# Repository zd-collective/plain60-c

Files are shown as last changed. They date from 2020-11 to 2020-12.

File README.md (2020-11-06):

# Plain60-C rev2.2 (Noctus edition)

This universal 60% PCB is designed to support as little layouts as possible without limiting usability for most users. The reason I did this is because other PCBs made for this form factor usually have so many supported layouts that it could almost qualify as swiss cheese.

It also features a fuse and an ESD protection chip to protect the MCU and other parts of the PCB.

## Modifications

- modified to use the same JST header position as the WT60 by Wilba
- holes for mounting of the weight on the Noctus
- removed the usb type-c port and related hardware
- added silkscreen onto the front
- removed standard poker mounting holes
- removed speaker

## Features
- Compatible with QMK Firmware and VIA Configurator (if you flash a VIA compatible .hex file)
- JST header for connection with daughterboard
- No LEDs and no underglow
- Minimal layout support
- ISP header

## Supported layouts
Supported layouts of the Plain60-C

## Building
If you feel like building a few of these PCBs yourself, go to the 'Releases' tab and download the latest gerber files. Order those at your favourite PCB manufacturer, get the components needed (see below) and solder them on! A hot air station is not required but a soldering iron is. Flux is recommended.

## Opening the project
To open the files you will need the latest KiCAD nightly version.

## Bill of materials (BOM)
Amount is per PCB, multiply as needed.

| LCSC part # | Description | Value | Package  | Amount |
| --- | --- | ----- | --- | ---:|
| C128353 | Capacitor | 0.1uF | 0805 | 4 |
| C131056 | Capacitor | 4.7uF | 0805 | 1 |
| C215803 | Capacitor | 1uF | 0805 | 1 |
| C109001 | Diode | | 0805 | 65 |
| C261942 | Fuse | | 0805 | 1 |
| C165948 | Connector | | SMD/THT  | 1 |
| C103904 | Resistor | 10K | 0805 | 2 |
| C212411 | Resistor | 5.1K  | 0805 | 2 |
| C325772 | Resistor | 22 | 0805 | 2 |
| C44854 | MCU | 32U4  | QFP-44 | 1 |
| C7519 | ESD chip | | SOT23-6  | 1 |
| C341521 | Resonator | 16MHz | SMD | 1 |
| C92584 | Switch | | SMD | 1 |
| C160404 | Optional JST  | | SMD | 1 |

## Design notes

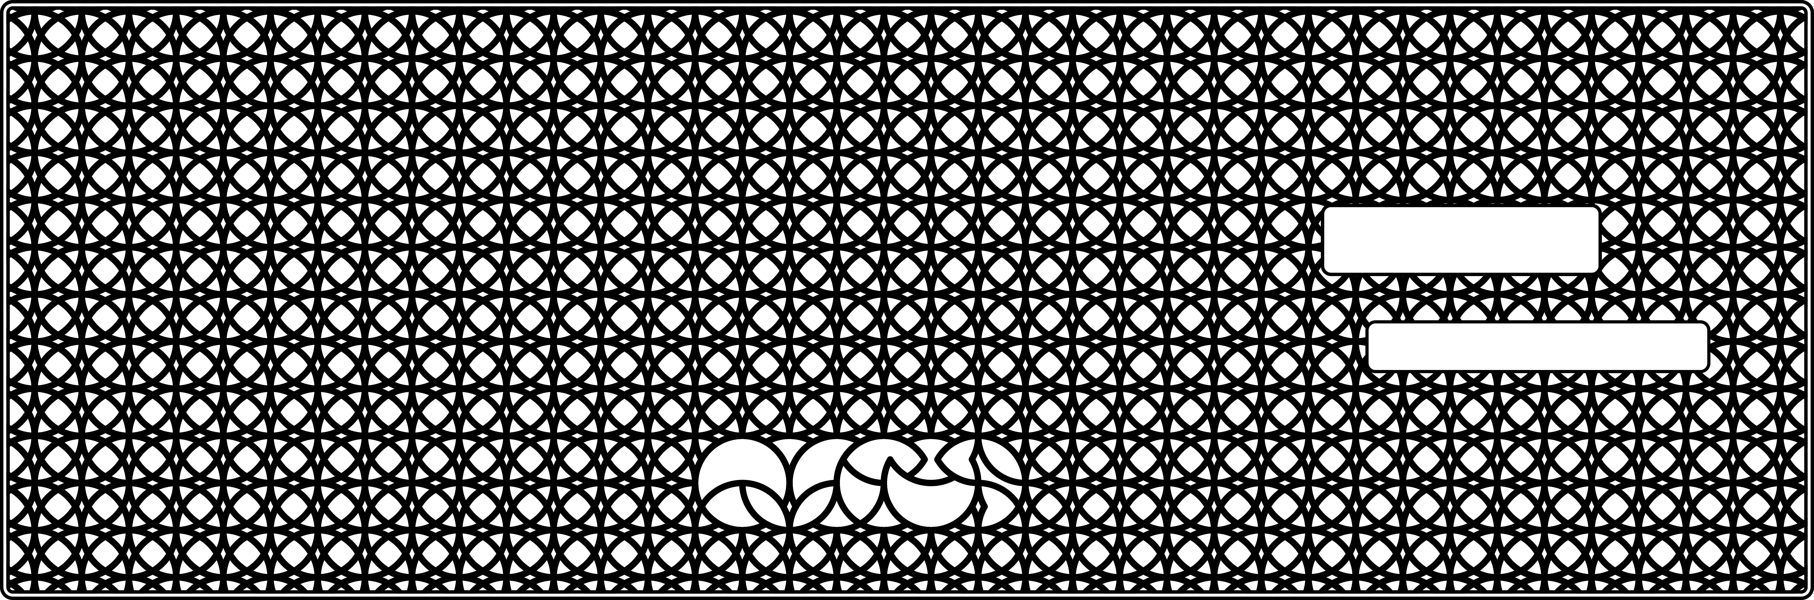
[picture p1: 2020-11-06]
noctus.png

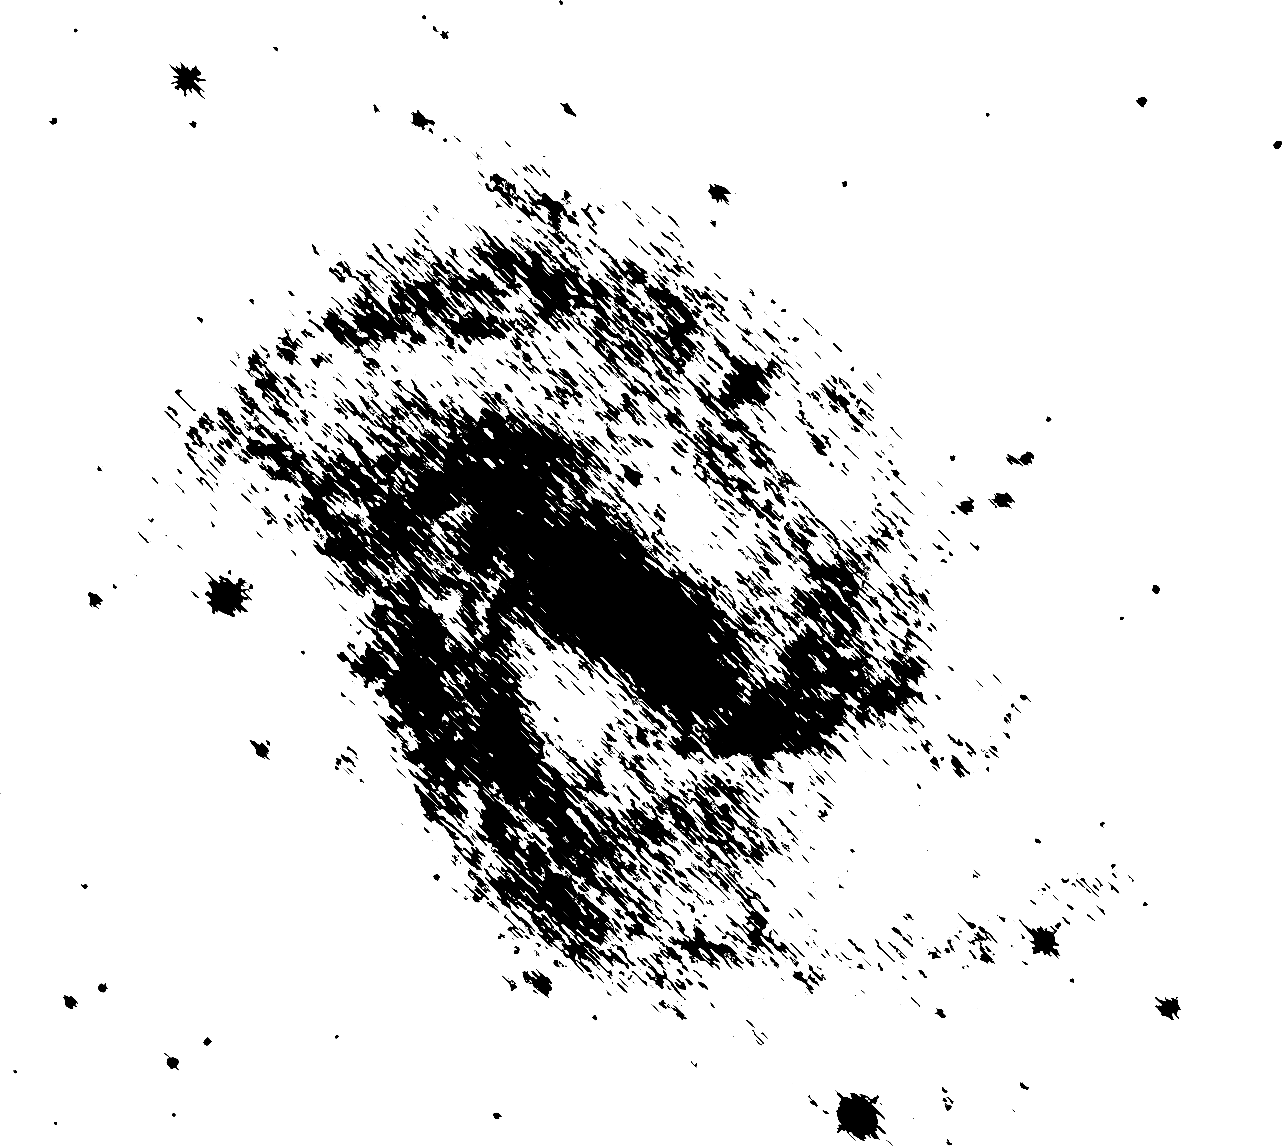
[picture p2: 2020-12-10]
galaxy.png

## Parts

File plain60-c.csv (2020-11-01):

Comment | Designator | Footprint | LCSC
1u | C1 | Keeb_components:C_0805
0.1u | C2,C3,C4,C5 | Keeb_components:C_0805
4.7u | C6 | Keeb_components:C_0805
D | D1,D2,D3,D4,D5,D6,D7,D8,D9,D10,D11,D12,D13,D14,D15,D16,D17,D18,D19,D20,D21,D22,D23,D24,D25,D26,D27,D28,D29,D31,D32,D33,D34,D35,D36,D37,D38,D39,D40,D41,D42,D43,D44,D46,D47,D48,D49,D50,D51,D52,D53,D54,D55,D56,D57,D58,D59,D61,D62,D63,D67,D71,D72,D73,D74 | Keeb_components:D_0805
Polyfuse | F1 | Keeb_components:R_0805
B0 | H1 | footprints:free_pin
GND | H3 | footprints:free_pin
+5v | H4 | footprints:free_pin
HRO-TYPE-C-31-M-12 | J1 | Keeb_components:HRO-TYPE-C-31-M-12
ISP | J2 | Keeb_components:isp_standard
ai03_ud | J3 | Keeb_components:JST_SH_SM04B-SRSS-TB_1x04-1MP_P1.00mm_Horizontal
KEYSW | K1,K2,K3,K4,K5,K6,K7,K8,K9,K10,K11,K12,K13,K14,K17,K18,K19,K20,K21,K22,K23,K24,K25,K26,K27,K28,K32,K33,K34,K35,K36,K37,K38,K39,K40,K41,K42,K43,K47,K48,K49,K50,K51,K52,K53,K54,K55,K56,K57,K59,K15-1,K62-1,K73-1 | Keeb_switches:CHERRY_PLATE_100H
KEYSW | K15 | Keeb_switches:CHERRY_PCB_200H
KEYSW | K16,K29,K61-1,K63-1,K72-1,K74-1 | Keeb_switches:CHERRY_PLATE_150H
KEYSW | K31,K58-1 | Keeb_switches:CHERRY_PLATE_175H
KEYSW | K44,K46 | Keeb_switches:CHERRY_PCB_225H
KEYSW | K44-1 | Keeb_switches:CHERRY_PCB_200H_V
KEYSW | K58 | Keeb_switches:CHERRY_PCB_275H
KEYSW | K61,K62,K63,K71,K72,K73,K74,K31-1,K46-1 | Keeb_switches:CHERRY_PLATE_125H
KEYSW | K67 | Keeb_switches:CHERRY_PCB_625H_F
KEYSW | K67-1 | Keeb_switches:CHERRY_PCB_700H_F
Speaker | LS1 | Keeb_components:speaker_AST1109MLTRQ
22 | R1,R2 | Keeb_components:R_0805
5.1k | R3,R4 | Keeb_components:R_0805
10k | R5,R6 | Keeb_components:R_0805
Screw | S1,S2,S3,S6 | footprints:5.5_5x2.5mm
Screw | S4,S5 | footprints:10x5_7x2.5mm
Tofu screw | S7,S8,S9 | footprints:5.5_5x2.5mm
SW_PUSH | SW1 | Button_Switch_SMD:SW_SPST_TL3342
ATmega32U4 | U1 | Keeb_components:ATMEGA32U4
USBLC6-2SC6 | U2 | Keeb_components:USBLC6-2SC6
XTAL_GND | X1 | Keeb_components:Resonator_SMD_muRata_CSTNExxV-3Pin-p1.2

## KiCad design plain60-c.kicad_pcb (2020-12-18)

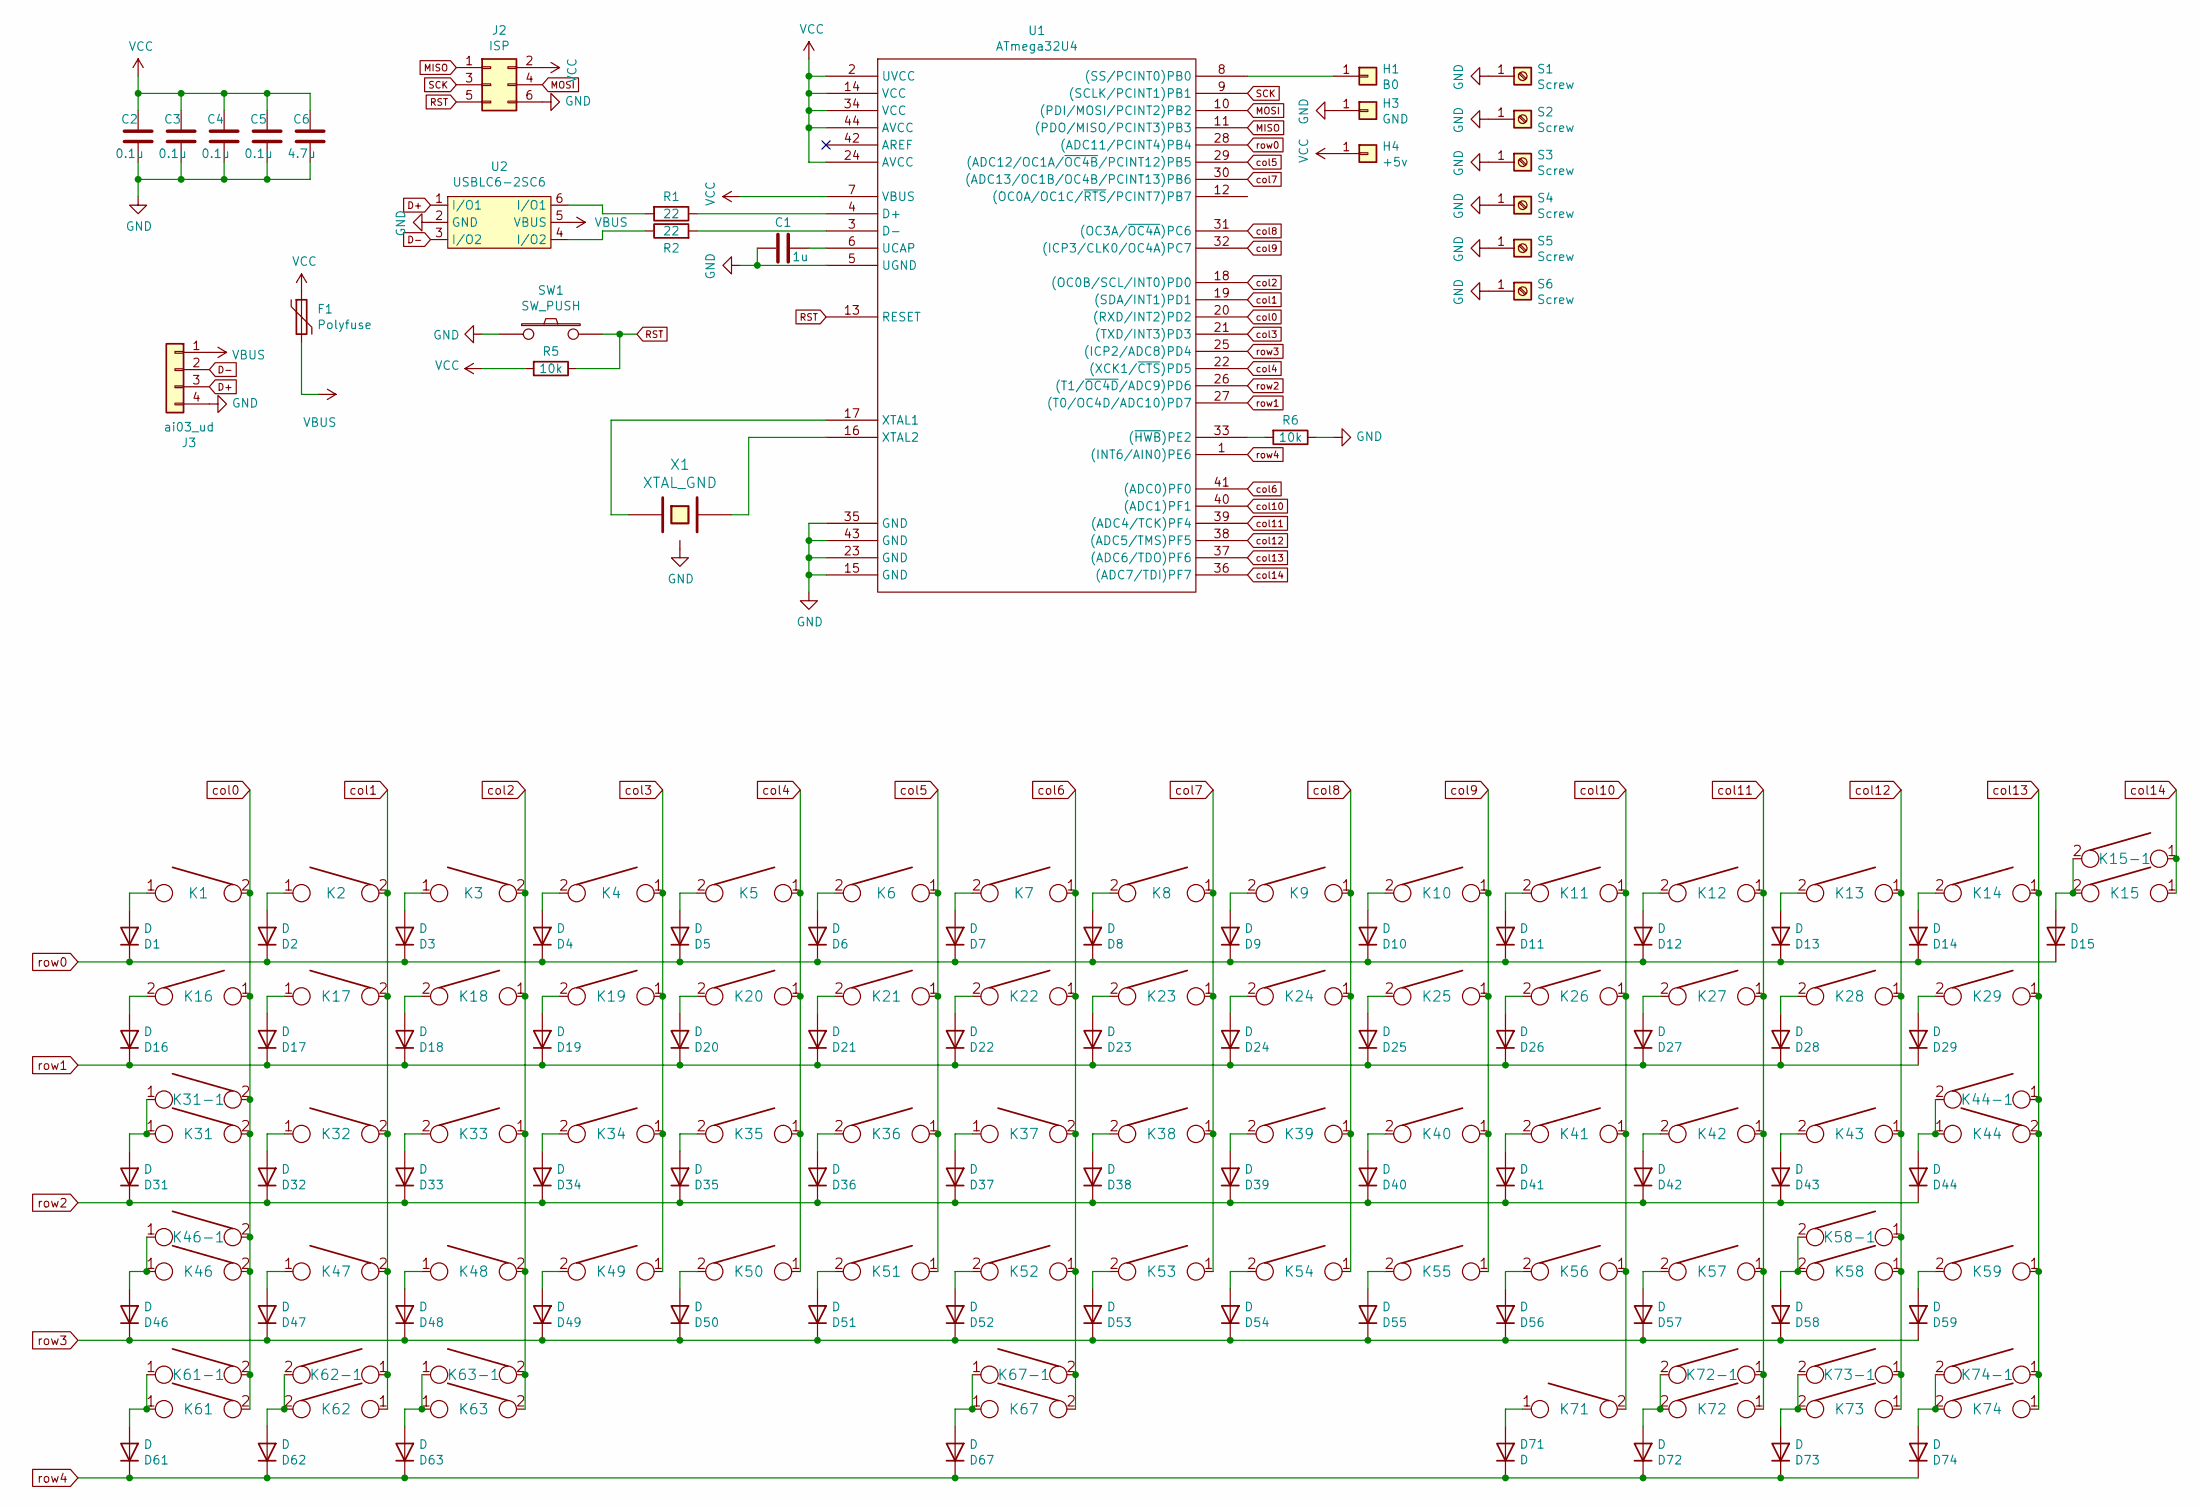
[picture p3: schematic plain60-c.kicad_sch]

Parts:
C1: 1u; C_0805
C2, C3, C4, C5: 0.1u; C_0805
C6: 4.7u; C_0805
D1, D2, D3, D4, D5, D6, D7, D8, D9, D10, D11, D12, D13, D14, D15, D16, D17, D18, D19, D20, D21, D22, D23, D24, D25, D26, D27, D28, D29, D31, D32, D33, D34, D35, D36, D37, D38, D39, D40, D41, D42, D43, D44, D46, D47, D48, D49, D50, D51, D52, D53, D54, D55, D56, D57, D58, D59, D61, D62, D63, D67, D71, D72, D73, D74: D; D_0805
F1: Polyfuse; R_0805
H1: B0; free_pin
H3: GND; free_pin
H4: +5v; free_pin
J2: ISP; isp_standard
J3: ai03_ud; JST_SH_SM04B-SRSS-TB_1x04-1MP_P1.00mm_Horizontal
K1, K2, K3, K4, K5, K6, K7, K8, K9, K10, K11, K12, K13, K14, K15-1, K17, K18, K19, K20, K21, K22, K23, K24, K25, K26, K27, K28, K32, K33, K34, K35, K36, K37, K38, K39, K40, K41, K42, K43, K47, K48, K49, K50, K51, K52, K53, K54, K55, K56, K57, K59, K62-1, K73-1: KEYSW; CHERRY_PLATE_100H
K15: KEYSW; CHERRY_PCB_200H
K16, K29, K61-1, K63-1, K72-1, K74-1: KEYSW; CHERRY_PLATE_150H
K31, K58-1: KEYSW; CHERRY_PLATE_175H
K31-1, K46-1, K61, K62, K63, K71, K72, K73, K74: KEYSW; CHERRY_PLATE_125H
K44, K46: KEYSW; CHERRY_PCB_225H
K44-1: KEYSW; CHERRY_PCB_200H_V
K58: KEYSW; CHERRY_PCB_275H
K67: KEYSW; CHERRY_PCB_625H_F
K67-1: KEYSW; CHERRY_PCB_700H_F
R1, R2: 22; R_0805
R5, R6: 10k; R_0805
S1, S2, S3, S6: Screw; 5.5_5x2.5mm
S4, S5: Screw; 10x5_7x2.5mm
SW1: SW_PUSH; SW_SPST_TL3342
U1: ATmega32U4; ATMEGA32U4
U2: USBLC6-2SC6; Farnell 1295310
X1: XTAL_GND; Resonator_SMD_muRata_CSTNExxV-3Pin-p1.2

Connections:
D+: J3.3, U2.1 (I/O1)
D-: J3.2, U2.3 (I/O2)
GND: C1.2, C2.1, C3.1, C4.1, C5.1, C6.1, H3.1, J2.6, J3.4, R6.1, S1.1, S2.1, S3.1, S4.1, S5.1, S6.1, SW1.1, U1.5 (UGND), U1.15 (GND), U1.23 (GND), U1.35 (GND), U1.43 (GND), U2.2 (GND), X1.3
MISO: J2.1, U1.11 ((PDO/MISO/PCINT3)PB3)
MOSI: J2.4, U1.10 ((PDI/MOSI/PCINT2)PB2)
unnamed: C1.1, U1.6 (UCAP)
unnamed: D1.2 (A), K1.1
unnamed: D2.2 (A), K2.1
unnamed: D3.2 (A), K3.1
unnamed: D4.2 (A), K4.2
unnamed: D5.2 (A), K5.2
unnamed: D6.2 (A), K6.2
unnamed: D7.2 (A), K7.2
unnamed: D8.2 (A), K8.2
unnamed: D9.2 (A), K9.2
unnamed: D10.2 (A), K10.2
unnamed: D11.2 (A), K11.2
unnamed: D12.2 (A), K12.2
unnamed: D13.2 (A), K13.2
unnamed: D14.2 (A), K14.2
unnamed: D15.2 (A), K15.2, K15-1.2
unnamed: D16.2 (A), K16.2
unnamed: D17.2 (A), K17.1
unnamed: D18.2 (A), K18.2
unnamed: D19.2 (A), K19.2
unnamed: D20.2 (A), K20.2
unnamed: D21.2 (A), K21.2
unnamed: D22.2 (A), K22.2
unnamed: D23.2 (A), K23.2
unnamed: D24.2 (A), K24.2
unnamed: D25.2 (A), K25.2
unnamed: D26.2 (A), K26.2
unnamed: D27.2 (A), K27.2
unnamed: D28.2 (A), K28.2
unnamed: D29.2 (A), K29.2
unnamed: D31.2 (A), K31.1, K31-1.1
unnamed: D32.2 (A), K32.1
unnamed: D33.2 (A), K33.2
unnamed: D34.2 (A), K34.2
unnamed: D35.2 (A), K35.2
unnamed: D36.2 (A), K36.2
unnamed: D37.2 (A), K37.1
unnamed: D38.2 (A), K38.2
unnamed: D39.2 (A), K39.2
unnamed: D40.2 (A), K40.2
unnamed: D41.2 (A), K41.2
unnamed: D42.2 (A), K42.2
unnamed: D43.2 (A), K43.2
unnamed: D44.2 (A), K44.1, K44-1.2
unnamed: D46.2 (A), K46.1, K46-1.1
unnamed: D47.2 (A), K47.1
unnamed: D48.2 (A), K48.1
unnamed: D49.2 (A), K49.2
unnamed: D50.2 (A), K50.2
unnamed: D51.2 (A), K51.2
unnamed: D52.2 (A), K52.2
unnamed: D53.2 (A), K53.2
unnamed: D54.2 (A), K54.2
unnamed: D55.2 (A), K55.2
unnamed: D56.2 (A), K56.2
unnamed: D57.2 (A), K57.2
unnamed: D58.2 (A), K58.2, K58-1.2
unnamed: D59.2 (A), K59.2
unnamed: D61.2 (A), K61.1, K61-1.1
unnamed: D62.2 (A), K62.2, K62-1.2
unnamed: D63.2 (A), K63.1, K63-1.1
unnamed: D67.2 (A), K67.1, K67-1.1
unnamed: D71.2 (A), K71.1
unnamed: D72.2 (A), K72.2, K72-1.2
unnamed: D73.2 (A), K73.2, K73-1.2
unnamed: D74.2 (A), K74.2, K74-1.2
unnamed: H1.1, U1.8 ((SS/PCINT0)PB0)
unnamed: R1.1, U1.4 (D+)
unnamed: R1.2, U2.6 (I/O1)
unnamed: R2.1, U2.4 (I/O2)
unnamed: R2.2, U1.3 (D-)
unnamed: R6.2, U1.33 ((~HWB~)PE2)
unnamed: U1.16 (XTAL2), X1.2
unnamed: U1.17 (XTAL1), X1.1
RST: J2.5, R5.1, SW1.2, U1.13 (RESET)
SCK: J2.3, U1.9 ((SCLK/PCINT1)PB1)
VBUS: F1.2, J3.1, U2.5 (VBUS)
VCC: C2.2, C3.2, C4.2, C5.2, C6.2, F1.1, H4.1, J2.2, R5.2, U1.2 (UVCC), U1.7 (VBUS), U1.14 (VCC), U1.24 (AVCC), U1.34 (VCC), U1.44 (AVCC)
col0: K1.2, K16.1, K31.2, K31-1.2, K46.2, K46-1.2, K61.2, K61-1.2, U1.20 ((RXD/INT2)PD2)
col1: K2.2, K17.2, K32.2, K47.2, K62.1, K62-1.1, U1.19 ((SDA/INT1)PD1)
col2: K3.2, K18.1, K33.1, K48.2, K63.2, K63-1.2, U1.18 ((OC0B/SCL/INT0)PD0)
col3: K4.1, K19.1, K34.1, K49.1, U1.21 ((TXD/INT3)PD3)
col4: K5.1, K20.1, K35.1, K50.1, U1.22 ((XCK1/~CTS~)PD5)
col5: K6.1, K21.1, K36.1, K51.1, U1.29 ((ADC12/OC1A/~OC4B~/PCINT12)PB5)
col6: K7.1, K22.1, K37.2, K52.1, K67.2, K67-1.2, U1.41 ((ADC0)PF0)
col7: K8.1, K23.1, K38.1, K53.1, U1.30 ((ADC13/OC1B/OC4B/PCINT13)PB6)
col8: K9.1, K24.1, K39.1, K54.1, U1.31 ((OC3A/~OC4A~)PC6)
col9: K10.1, K25.1, K40.1, K55.1, U1.32 ((ICP3/CLK0/OC4A)PC7)
col10: K11.1, K26.1, K41.1, K56.1, K71.2, U1.40 ((ADC1)PF1)
col11: K12.1, K27.1, K42.1, K57.1, K72.1, K72-1.1, U1.39 ((ADC4/TCK)PF4)
col12: K13.1, K28.1, K43.1, K58.1, K58-1.1, K73.1, K73-1.1, U1.38 ((ADC5/TMS)PF5)
col13: K14.1, K29.1, K44.2, K44-1.1, K59.1, K74.1, K74-1.1, U1.37 ((ADC6/TDO)PF6)
col14: K15.1, K15-1.1, U1.36 ((ADC7/TDI)PF7)
row0: D1.1 (K), D2.1 (K), D3.1 (K), D4.1 (K), D5.1 (K), D6.1 (K), D7.1 (K), D8.1 (K), D9.1 (K), D10.1 (K), D11.1 (K), D12.1 (K), D13.1 (K), D14.1 (K), D15.1 (K), U1.28 ((ADC11/PCINT4)PB4)
row1: D16.1 (K), D17.1 (K), D18.1 (K), D19.1 (K), D20.1 (K), D21.1 (K), D22.1 (K), D23.1 (K), D24.1 (K), D25.1 (K), D26.1 (K), D27.1 (K), D28.1 (K), D29.1 (K), U1.27 ((T0/OC4D/ADC10)PD7)
row2: D31.1 (K), D32.1 (K), D33.1 (K), D34.1 (K), D35.1 (K), D36.1 (K), D37.1 (K), D38.1 (K), D39.1 (K), D40.1 (K), D41.1 (K), D42.1 (K), D43.1 (K), D44.1 (K), U1.26 ((T1/~OC4D~/ADC9)PD6)
row3: D46.1 (K), D47.1 (K), D48.1 (K), D49.1 (K), D50.1 (K), D51.1 (K), D52.1 (K), D53.1 (K), D54.1 (K), D55.1 (K), D56.1 (K), D57.1 (K), D58.1 (K), D59.1 (K), U1.25 ((ICP2/ADC8)PD4)
row4: D61.1 (K), D62.1 (K), D63.1 (K), D67.1 (K), D71.1 (K), D72.1 (K), D73.1 (K), D74.1 (K), U1.1 ((INT6/AIN0)PE6)

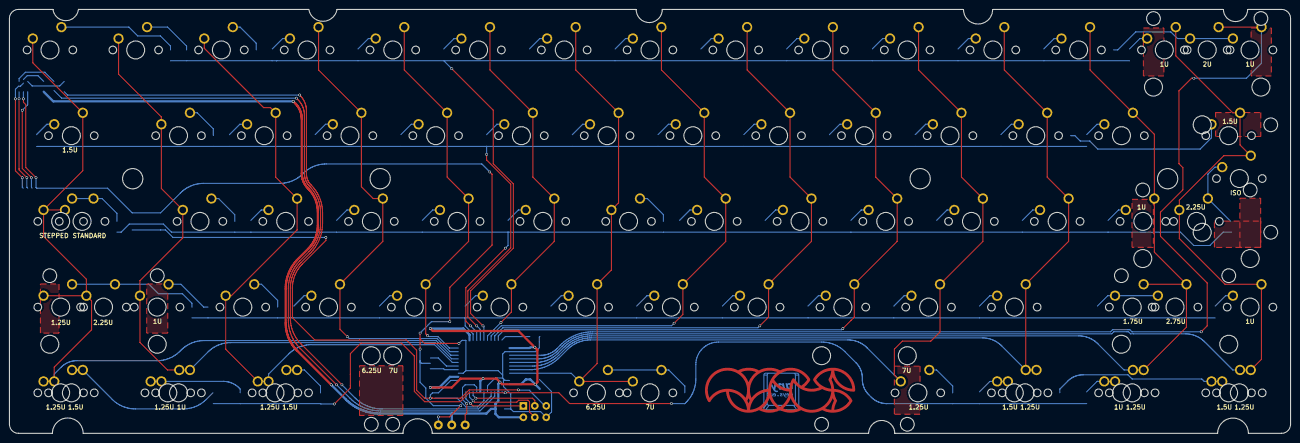
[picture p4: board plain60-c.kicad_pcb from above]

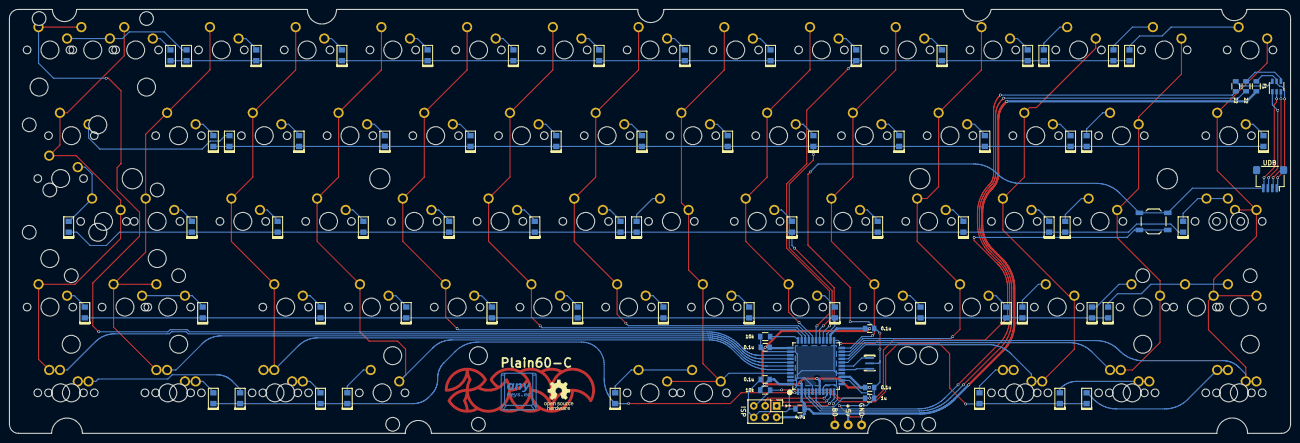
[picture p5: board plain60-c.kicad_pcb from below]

Board: 2 copper layers, 284.7 x 94.2 mm, 162 parts (85 on the bottom side), 103 nets.

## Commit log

2020-10-30 add holes and move jst position
    [plain60-c.kicad_pcb]
2020-10-31 readme updated also added holes and shit
    [plain60-c.kicad_pcb]
2020-11-06 remove usb-c and add back silkscreen
    [plain60-c.kicad_sch]
2020-11-06 changed silk, removed poker mounts
    [plain60-c.kicad_sch]
2020-11-09 rounded traces and updated gerbers
    [plain60-c-B_Cu.gbr, plain60-c-B_Fab.gbr, plain60-c-B_Mask.gbr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]
2020-11-17 add soldermask and fix trace
    [plain60-c.kicad_pcb]
2020-11-18 fixed some traces and redo gerber
    [plain60-c-B_Cu.gbr, plain60-c-B_Fab.gbr, plain60-c-B_Mask.gbr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]
2020-12-10 add side cuts
    [plain60-c-B_Cu.gbr, plain60-c-B_Fab.gbr, plain60-c-B_Mask.gbr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]
2020-12-18 edited traces
    [plain60-c.kicad_pcb]
